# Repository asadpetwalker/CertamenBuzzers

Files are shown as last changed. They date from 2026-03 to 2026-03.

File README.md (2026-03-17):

# CertamenBuzzers

A buzzer system for the game Certamen about Roman language, mythology, history, and culture. It is a quiz bowl style game, where whoever buzzes first gets a chance to claim the points.

# Why I made this

I made this because right now buzzer systems are inaccessible. Buzzer systems are sold by JCL, but they have a monopoly over it, so they mark up the prices incredibly even though the electronics are fairly simple, to 800 dollars. for the small version. I made this for my team, because they need a buzzer system to get practice in, since hyperbuzzing is an important strategy in more competitive leagues, as well as the fact that the current version is very bulky and you cannot bring it to places for practice.

# Wiring Diagram

Wire - Button - Wire

# Pictures

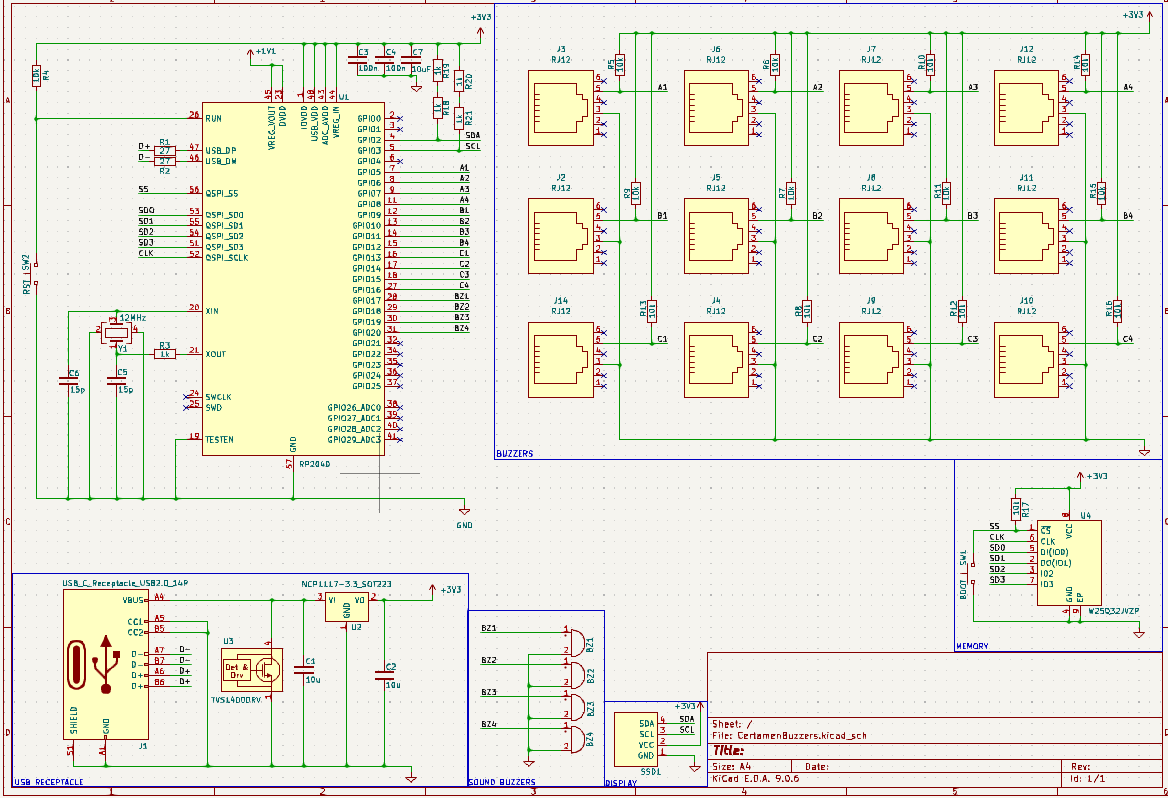
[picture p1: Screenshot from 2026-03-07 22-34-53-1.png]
 
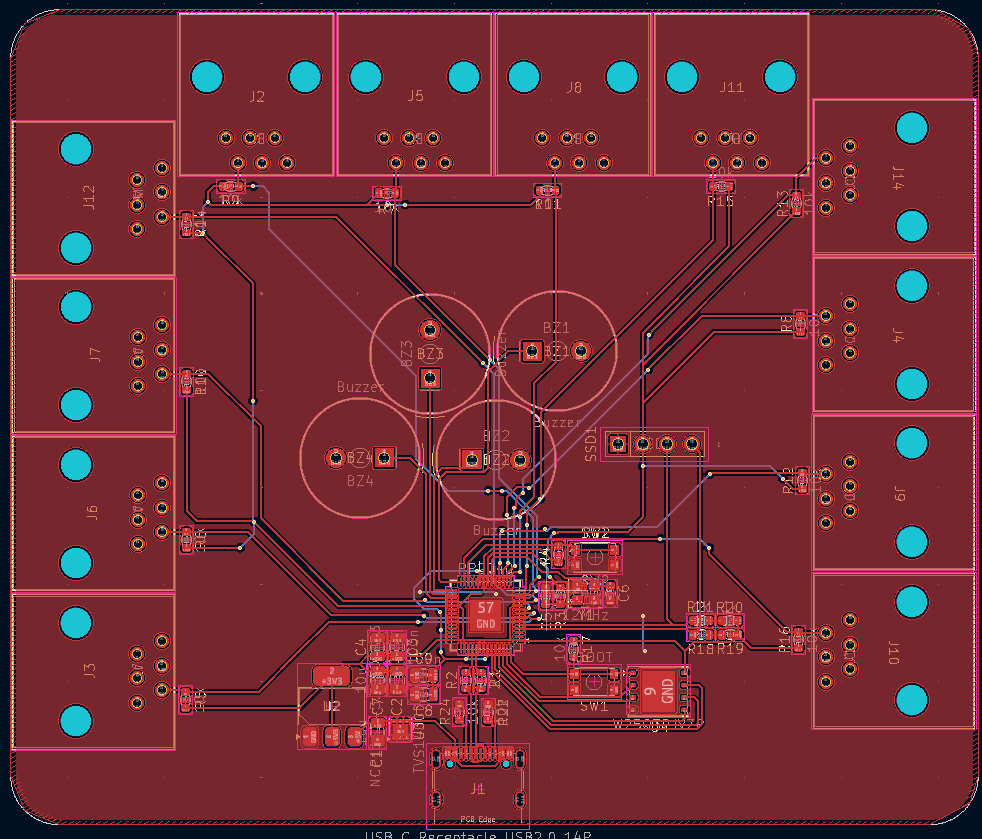
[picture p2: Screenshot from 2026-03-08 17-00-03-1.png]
 
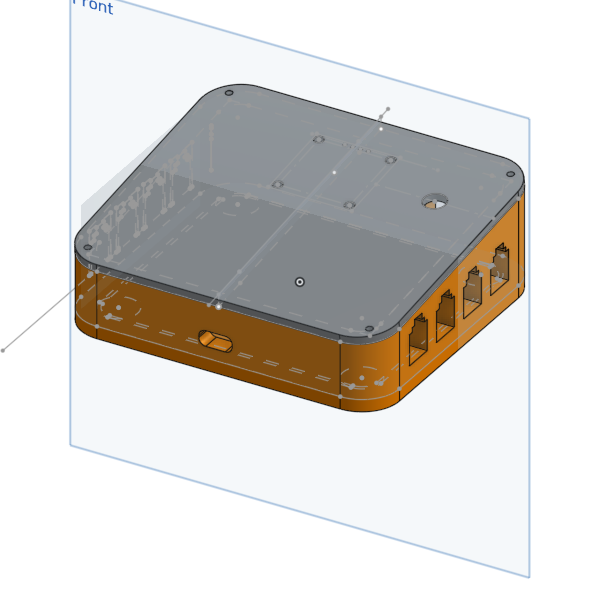
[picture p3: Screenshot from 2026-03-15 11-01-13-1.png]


# BOM

| Name | Purpose | Cost | Qty | Total Cost | Link | Supplier |
|-----|-----|-----|-----|-----|-----|-----|
| GLF-464-144-521-D | Cables for Buzzers | $1.73 | 6 | $10.38 | https://www.digikey.com/en/products/detail/i-o-interconnect/GLF-464-144-521-D/773066 | DigiKey |
| 12 Buttons | Buzzers | $7.69 | 1 | $7.69 | https://www.amazon.com/MKBKLLJY-Latching-Button-Self-Locking-Terminal/dp/B0CPXMVL59 | Amazon |
| 27Ω Resistor | MCU | $0.01 | 10 | $0.06 | https://www.digikey.com/en/products/detail/yageo/RC0603FR-0727RL/727099 | DigiKey |
| 15pF Capacitor | Crystal Oscillator | $0.03 | 10 | $0.33 | https://www.digikey.com/en/products/detail/yageo/CC0603JRNPO9BN150/302794 | DigiKey |
| 1k Resistor | MCU | $0.01 | 10 | $0.06 | https://www.digikey.com/en/products/detail/stackpole-electronics-inc/RMCF0603FT1K00/1761077 | DigiKey |
| W25Q64JVZPIQ | Memory | $1.43 | 1 | $1.43 | https://www.digikey.com/en/products/detail/winbond-electronics/W25Q64JVZPIQ/15181953 | DigiKey |
| 10k Resistors | Buzzers | $0.00 | 25 | $0.12 | https://www.digikey.com/en/products/detail/stackpole-electronics-inc/RMCF0402FT10K0/1761433 | DigiKey |
| 12MHz Crystal | RP2040 | $0.45 | 1 | $0.45 | https://www.digikey.com/en/products/detail/abracon-llc/ABM10-166-12-000MHZ-T3/6140263 | DigiKey |
| RP2040 | MCU | $0.70 | 1 | $0.70 | https://www.digikey.com/en/products/detail/raspberry-pi/SC0914-13/14306010 | DigiKey |
| MTJ-662BX2 | Receptacle for cable buzzers | $0.21 | 12 | $2.56 | https://www.digikey.com/en/products/detail/adam-tech/MTJ-662BX2/9832250 | DigiKey |
| TVS1400 | Transient Suppression | $0.57 | 1 | $0.57 | https://www.digikey.com/en/products/detail/texas-instruments/TVS1400DRVR/8566097 | DigiKey |
| 100nF Capacitor | For RP2040 | $0.01 | 10 | $0.12 | https://www.digikey.com/en/products/detail/yageo/CC0805KRX7R9BB104/302874 | DigiKey |
| 10µF Capacitor | NCP117 | $0.02 | 10 | $0.16 | https://www.digikey.com/en/products/detail/taiyo-yuden/LMK212BJ106KG-T/930652 | DigiKey |
| KMR24 | Control Buttons | $0.67 | 2 | $1.34 | https://www.digikey.com/en/products/detail/c-k/KMR241NG-ULC-LFS/2043217 | DigiKey |
| USB4105 | USB For Programming MCU | $0.78 | 1 | $0.78 | https://www.digikey.com/en/products/detail/gct/USB4105-GF-A-120/14559037 | DigiKey |
| PS1240 | Buzzer for buzzing | $0.57 | 4 | $2.28 | https://www.digikey.com/en/products/detail/tdk-corporation/PS1240P02BT/935924 | DigiKey |
| NCP1117-3.3 | 3.3V LDO | $0.37 | 1 | $0.37 | https://www.digikey.com/en/products/detail/onsemi/NCP1117LPST33T3G/2194024 | DigiKey |
| PS102 | Button for resetting | $1.55 | 1 | $1.55 | https://www.digikey.com/en/products/detail/e-switch/PS1024ABLK/81742 | DigiKey |

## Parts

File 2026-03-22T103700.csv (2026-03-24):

Index | Quantity | Part Number | Manufacturer Part Number | Description | Customer Reference | Available | Backorder | Unit Price | Extended Price USD
1 | 1 | NCP1117LPST33T3GOSCT-ND | NCP1117LPST33T3G | IC REG LINEAR 3.3V 1A SOT-223 |  | 1 | 0 | 0.37000 | 0.37
2 | 4 | 445-2525-1-ND | PS1240P02BT | BUZZER PIEZO 3V 12.2MM TH |  | 4 | 0 | 0.57000 | 2.28
3 | 1 | 2073-USB4105-GF-A-120CT-ND | USB4105-GF-A-120 | CONN RCP USB2.0 TYP C 16P SMD RA |  | 1 | 0 | 0.78000 | 0.78
4 | 2 | CKN10285CT-ND | KMR241NG ULC LFS | SWITCH TACTILE SPST-NO 0.05A 32V |  | 2 | 0 | 0.67000 | 1.34
5 | 10 | 587-1300-1-ND | LMK212BJ106KG-T | CAP CER 10UF 10V X5R 0805 |  | 10 | 0 | 0.01600 | 0.16
6 | 10 | 311-1140-1-ND | CC0805KRX7R9BB104 | CAP CER 0.1UF 50V X7R 0805 |  | 10 | 0 | 0.05500 | 0.55
7 | 10 | 399-C0805C104K5RACTUCT-ND | C0805C104K5RACTU | CAP CER 0.1UF 50V X7R 0805 |  | 10 | 0 | 0.01600 | 0.16
8 | 1 | 296-50511-1-ND | TVS1400DRVR | UNIDIR PRECISION SURGE DIODE |  | 1 | 0 | 0.57000 | 0.57
9 | 12 | 2057-MTJ-662BX2-ND | MTJ-662BX2 | CONN MOD JACK 6P6C R/A UNSHIELD |  | 12 | 0 | 0.24500 | 2.94
10 | 1 | 535-13520-1-ND | ABM10-166-12.000MHZ-T3 | CRYSTAL 12.0000MHZ 8PF SMD |  | 1 | 0 | 0.45000 | 0.45
11 | 25 | RMCF0402FT10K0CT-ND | RMCF0402FT10K0 | RES 10K OHM 1% 1/16W 0402 |  | 25 | 0 | 0.00480 | 0.12
12 | 1 | 256-W25Q64JVZPIQ-TRAY-ND | W25Q64JVZPIQ | IC FLASH 64MBIT SPI/QUAD 8WSON |  | 1 | 0 | 1.43000 | 1.43
13 | 10 | RMCF0603FT1K00CT-ND | RMCF0603FT1K00 | RES 1K OHM 1% 1/10W 0603 |  | 10 | 0 | 0.00600 | 0.06
14 | 10 | 311-1060-1-ND | CC0603JRNPO9BN150 | CAP CER 15PF 50V C0G/NPO 0603 |  | 10 | 0 | 0.03300 | 0.33
15 | 10 | 311-27.0HRCT-ND | RC0603FR-0727RL | RES 27 OHM 1% 1/10W 0603 |  | 10 | 0 | 0.00600 | 0.06
16 | 6 | H3642R-14-ND | GLF-464-144-521-D | CABLE MOD 6P4C PLUG TO CABLE 14' |  | 6 | 0 | 1.73000 | 10.38
17 | 4 | EG2011-ND | PS1024ABLK | SWITCH PUSH SPST-NO 3A 125V |  | 4 | 0 | 1.55000 | 6.20
18 | 2 | 2648-SC0914(7)CT-ND | SC0914(7) | IC MCU 32B EXT MEM 56QFN RP2040 |  | 2 | 0 | 0.80000 | 1.60

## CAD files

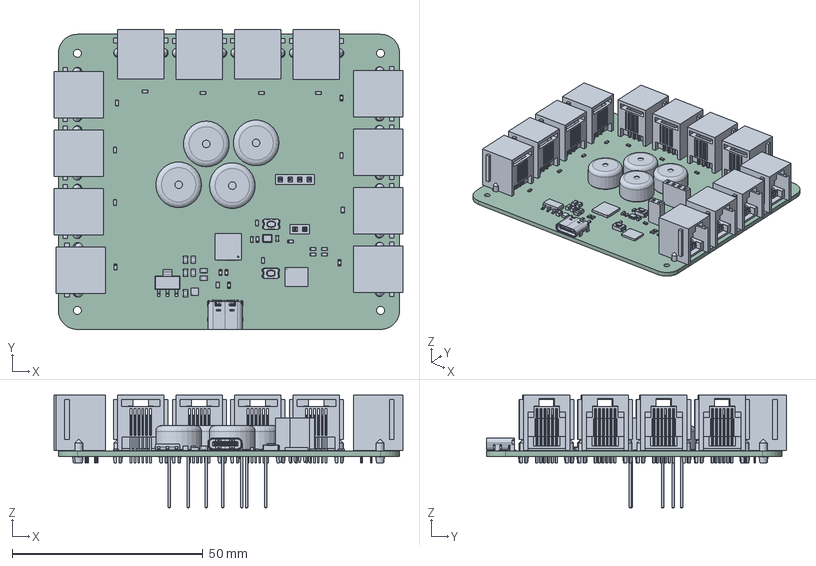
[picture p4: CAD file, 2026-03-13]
CertamenBuzzers/CertamenBuzzers.step
91.5 x 78.7 x 29.5 mm
C_0805_2012Metric x 7
MTJ-662BX2 x 12
SW_Push_1P1T_NO_CK_KMR2 x 2
R_0603_1608Metric x 24
SOT-223
PinSocket_1x02_P2.54mm_Vertical
USB_C_Receptacle_GCT_USB4105-xx-A_16P_TopMnt_Horizontal
WSON-8-1EP_6x5mm_P1.27mm_EP3.4x4.3mm
Buzzer_TDK_PS1240P02BT_D12.2mm_H6.5mm x 4
C_0603_1608Metric x 2
QFN-56-1EP_7x7mm_P0.4mm_EP3.2x3.2mm
PinSocket_1x04_P2.54mm_Vertical
Crystal_SMD_2520-4Pin_2.5x2.0mm
WSON-6-1EP_2x2mm_P0.65mm_EP1x1.6mm
CertamenBuzzers_PCB

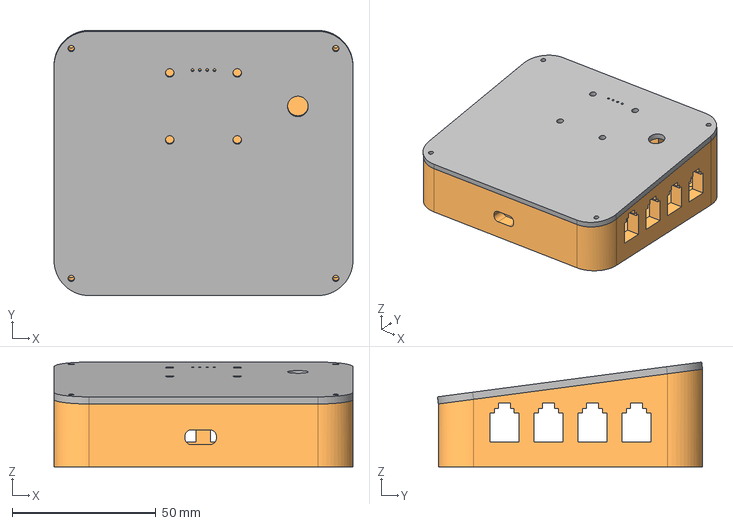
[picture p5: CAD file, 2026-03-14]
BuzzerCase.step
104.0 x 92.2 x 36.5 mm

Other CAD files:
CertamenBuzzers.sldprt

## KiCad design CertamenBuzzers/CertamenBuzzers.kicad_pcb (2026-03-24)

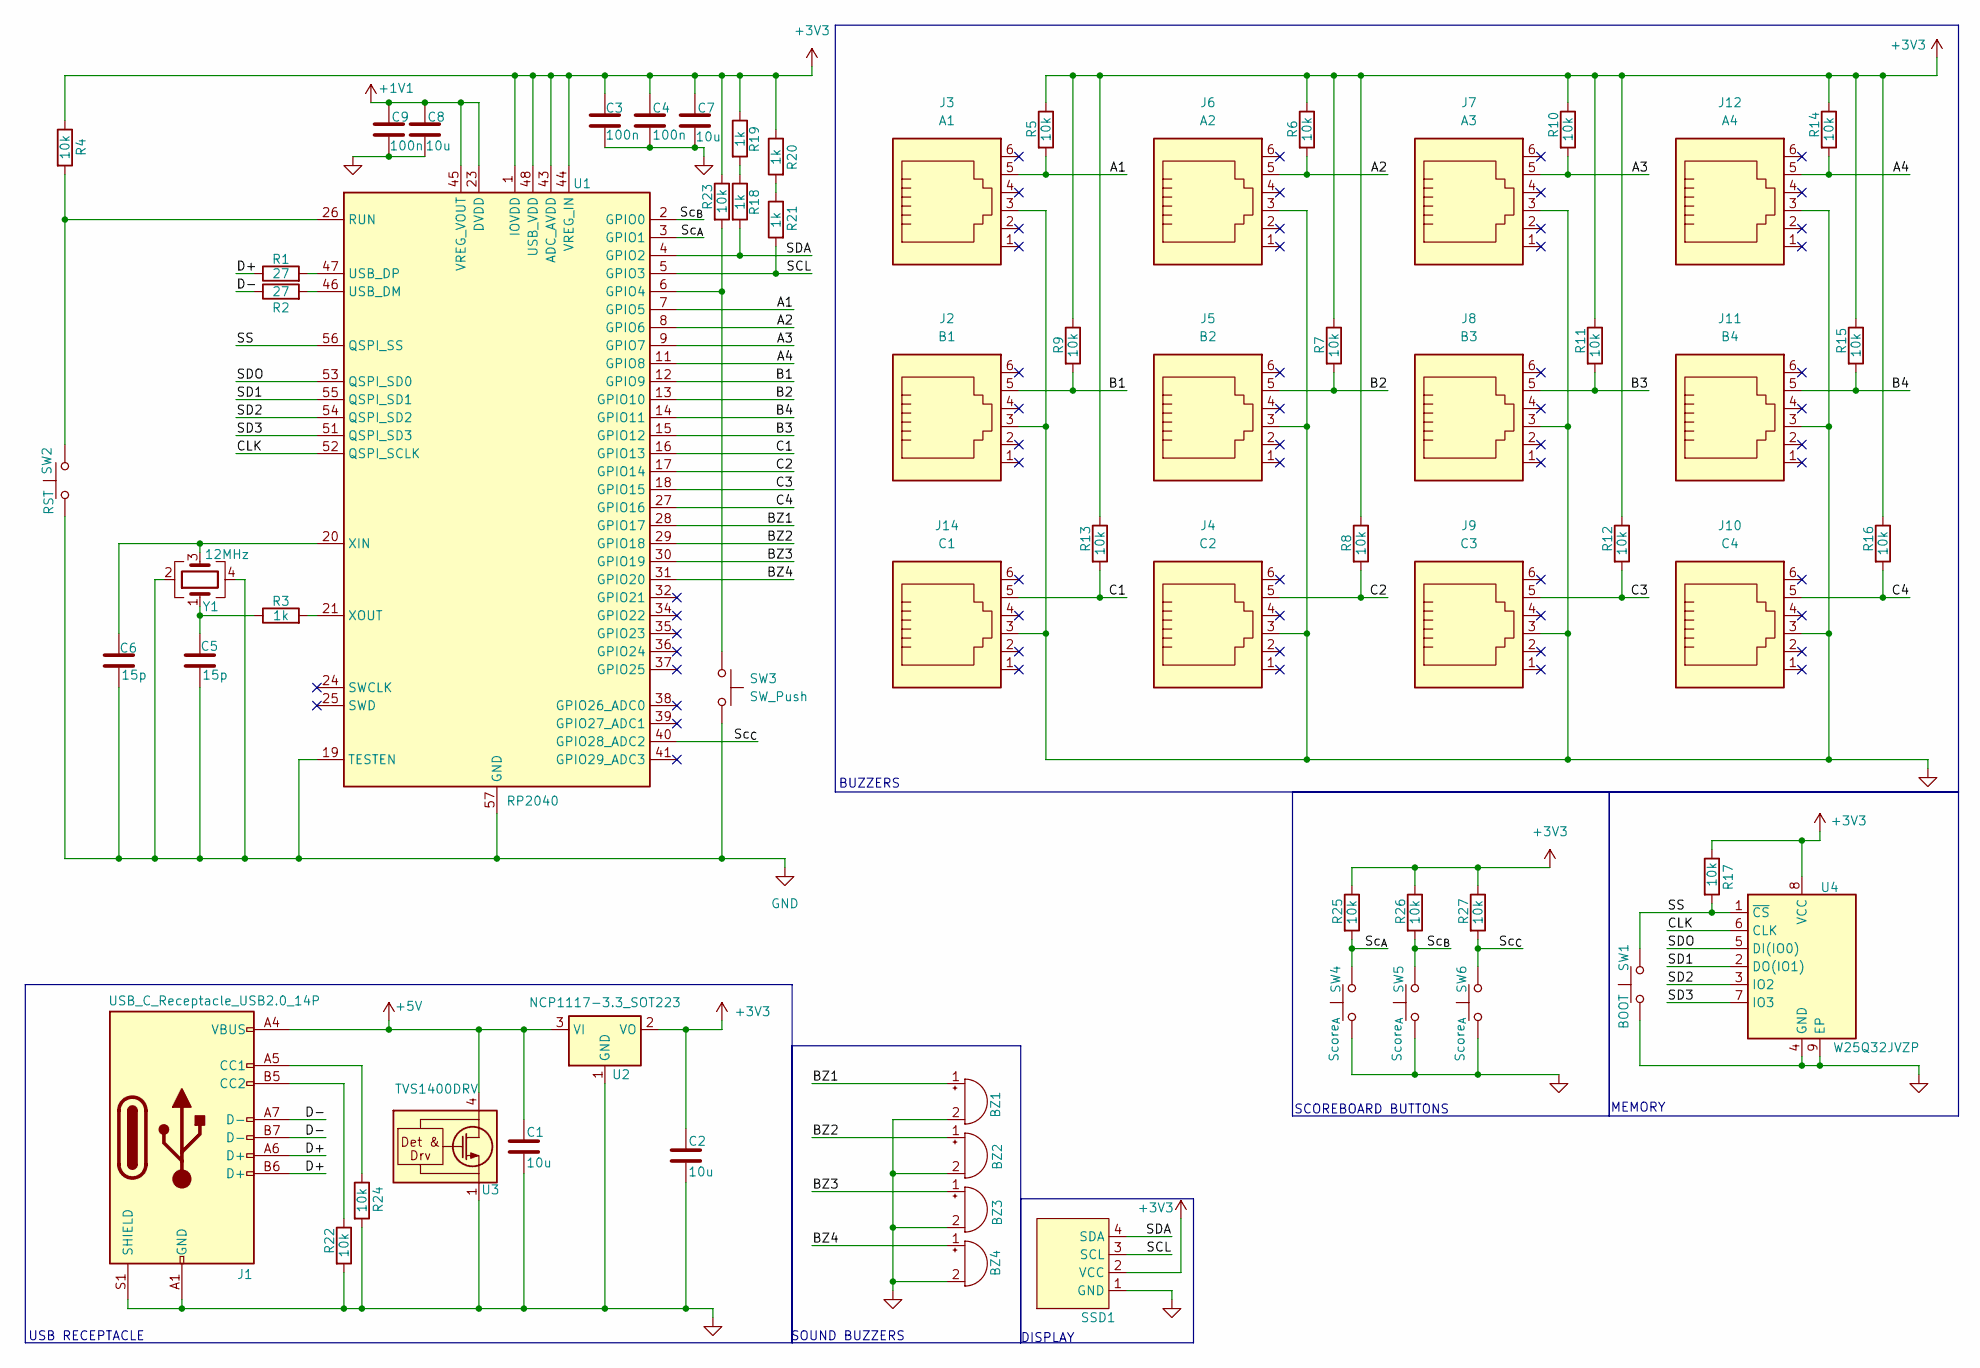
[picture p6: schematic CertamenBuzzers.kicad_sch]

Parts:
BZ1, BZ2, BZ3, BZ4: Buzzer; Buzzer_TDK_PS1240P02BT_D12.2mm_H6.5mm
C1, C2, C7, C8: 10u; C_0805_2012Metric
C3, C4, C9: 100n; C_0805_2012Metric
C5, C6: 15p; C_0603_1608Metric
J1: USB_C_Receptacle_USB2.0_14P; USB_C_Receptacle_GCT_USB4105-xx-A_16P_TopMnt_Horizontal
J2: B1; RJ25_Wayconn_MJEA-660X1_Horizontal
J3: A1; RJ25_Wayconn_MJEA-660X1_Horizontal
J4: C2; RJ25_Wayconn_MJEA-660X1_Horizontal
J5: B2; RJ25_Wayconn_MJEA-660X1_Horizontal
J6: A2; RJ25_Wayconn_MJEA-660X1_Horizontal
J7: A3; RJ25_Wayconn_MJEA-660X1_Horizontal
J8: B3; RJ25_Wayconn_MJEA-660X1_Horizontal
J9: C3; RJ25_Wayconn_MJEA-660X1_Horizontal
J10: C4; RJ25_Wayconn_MJEA-660X1_Horizontal
J11: B4; RJ25_Wayconn_MJEA-660X1_Horizontal
J12: A4; RJ25_Wayconn_MJEA-660X1_Horizontal
J14: C1; RJ25_Wayconn_MJEA-660X1_Horizontal
R1, R2: 27; R_0603_1608Metric
R3, R18, R19, R20, R21: 1k; R_0603_1608Metric
R4, R5, R6, R7, R8, R9, R10, R11, R12, R13, R14, R15, R16, R17, R22, R23, R24, R25, R26, R27: 10k; R_0603_1608Metric
SSD1: PinSocket_1x04_P2.54mm_Vertical
SW1: BOOT; SW_Push_1P1T_NO_CK_KMR2
SW2: RST; SW_Push_1P1T_NO_CK_KMR2
SW3: SW_Push; PinSocket_1x02_P2.54mm_Vertical
SW4, SW5, SW6: Score_{A}; PinSocket_1x02_P2.54mm_Vertical
U1: RP2040; QFN-56-1EP_7x7mm_P0.4mm_EP3.2x3.2mm
U2: NCP1117-3.3_SOT223; SOT-223-3_TabPin2
U3: TVS1400DRV; WSON-6-1EP_2x2mm_P0.65mm_EP1x1.6mm
U4: W25Q32JVZP; WSON-8-1EP_6x5mm_P1.27mm_EP3.4x4.3mm
Y1: 12MHz; Crystal_SMD_2520-4Pin_2.5x2.0mm

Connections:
+1V1: C8.1, C9.1, U1.23 (DVDD), U1.45 (VREG_VOUT), U1.50 (DVDD)
+3V3: C2.1, C3.1, C4.1, C7.1, R4.1, R5.1, R6.1, R7.1, R8.1, R9.1, R10.1, R11.1, R12.1, R13.1, R14.1, R15.1, R16.1, R17.1, R19.1, R20.1, R23.1, R25.1, R26.1, R27.1, SSD1.2 (VCC), U1.1 (IOVDD), U1.10 (IOVDD), U1.22 (IOVDD), U1.33 (IOVDD), U1.42 (IOVDD), U1.43 (ADC_AVDD), U1.44 (VREG_IN), U1.48 (USB_VDD), U1.49 (IOVDD), U2.2 (VO), U4.8 (VCC)
+5V: C1.1, J1.A4 (VBUS), J1.A9 (VBUS), J1.B4 (VBUS), J1.B9 (VBUS), U2.3 (VI), U3.4 (IN), U3.5 (IN), U3.6 (IN)
/A1: J3.5, R5.2, U1.7 (GPIO5)
/A2: J6.5, R6.2, U1.8 (GPIO6)
/A3: J7.5, R10.2, U1.9 (GPIO7)
/A4: J12.5, R14.2, U1.11 (GPIO8)
/B1: J2.5, R9.2, U1.12 (GPIO9)
/B2: J5.5, R7.2, U1.13 (GPIO10)
/B3: J8.5, R11.2, U1.15 (GPIO12)
/B4: J11.5, R15.2, U1.14 (GPIO11)
/BZ1: BZ1.1 (+), U1.28 (GPIO17)
/BZ2: BZ2.1 (+), U1.29 (GPIO18)
/BZ3: BZ3.1 (+), U1.30 (GPIO19)
/BZ4: BZ4.1 (+), U1.31 (GPIO20)
/C1: J14.5, R13.2, U1.16 (GPIO13)
/C2: J4.5, R8.2, U1.17 (GPIO14)
/C3: J9.5, R12.2, U1.18 (GPIO15)
/C4: J10.5, R16.2, U1.27 (GPIO16)
/CLK: U1.52 (QSPI_SCLK), U4.6 (CLK)
/D+: J1.A6 (D+), J1.B6 (D+), R1.1
/D-: J1.A7 (D-), J1.B7 (D-), R2.1
/SCL: R21.2, SSD1.3 (SCL), U1.5 (GPIO3)
/SD1: U1.55 (QSPI_SD1), U4.2 (DO(IO1))
/SD2: U1.54 (QSPI_SD2), U4.3 (IO2)
/SD3: U1.51 (QSPI_SD3), U4.7 (IO3)
/SDA: R18.2, SSD1.4 (SDA), U1.4 (GPIO2)
/SDO: U1.53 (QSPI_SD0), U4.5 (DI(IO0))
/SS: R17.2, SW1.2, U1.56 (QSPI_SS), U4.1 (~CS)
/Sc_{A}: R25.2, SW4.2, U1.3 (GPIO1)
/Sc_{B}: R26.2, SW5.2, U1.2 (GPIO0)
/Sc_{C}: R27.2, SW6.2, U1.40 (GPIO28_ADC2)
GND: BZ1.2 (-), BZ2.2 (-), BZ3.2 (-), BZ4.2 (-), C1.2, C2.2, C3.2, C4.2, C5.2, C6.2, C7.2, C8.2, C9.2, J1.A1 (GND), J1.A12 (GND), J1.B1 (GND), J1.B12 (GND), J1.S1 (SHIELD), J2.3, J3.3, J4.3, J5.3, J6.3, J7.3, J8.3, J9.3, J10.3, J11.3, J12.3, J14.3, R22.2, R24.2, SSD1.1 (GND), SW1.1, SW2.1, SW3.2, SW4.1, SW5.1, SW6.1, U1.19 (TESTEN), U1.57 (GND), U2.1 (GND), U3.1 (GND), U3.2 (GND), U3.3 (GND), U3.7 (GND), U4.4 (GND), U4.9 (EP), Y1.2, Y1.4
unnamed: C5.1, R3.1, Y1.1
unnamed: J1.A5 (CC1), R24.1
unnamed: J1.B5 (CC2), R22.1
unnamed: R18.1, R19.2
unnamed: R20.2, R21.1
unnamed: R23.2, SW3.1, U1.6 (GPIO4)
unnamed: R4.2, SW2.2, U1.26 (RUN)
unnamed: R2.2, U1.46 (USB_DM)
unnamed: R1.2, U1.47 (USB_DP)
unnamed: C6.1, U1.20 (XIN), Y1.3
unnamed: R3.2, U1.21 (XOUT)

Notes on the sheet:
SCOREBOARD BUTTONS
USB RECEPTACLE
SOUND BUZZERS
DISPLAY
BUZZERS
MEMORY

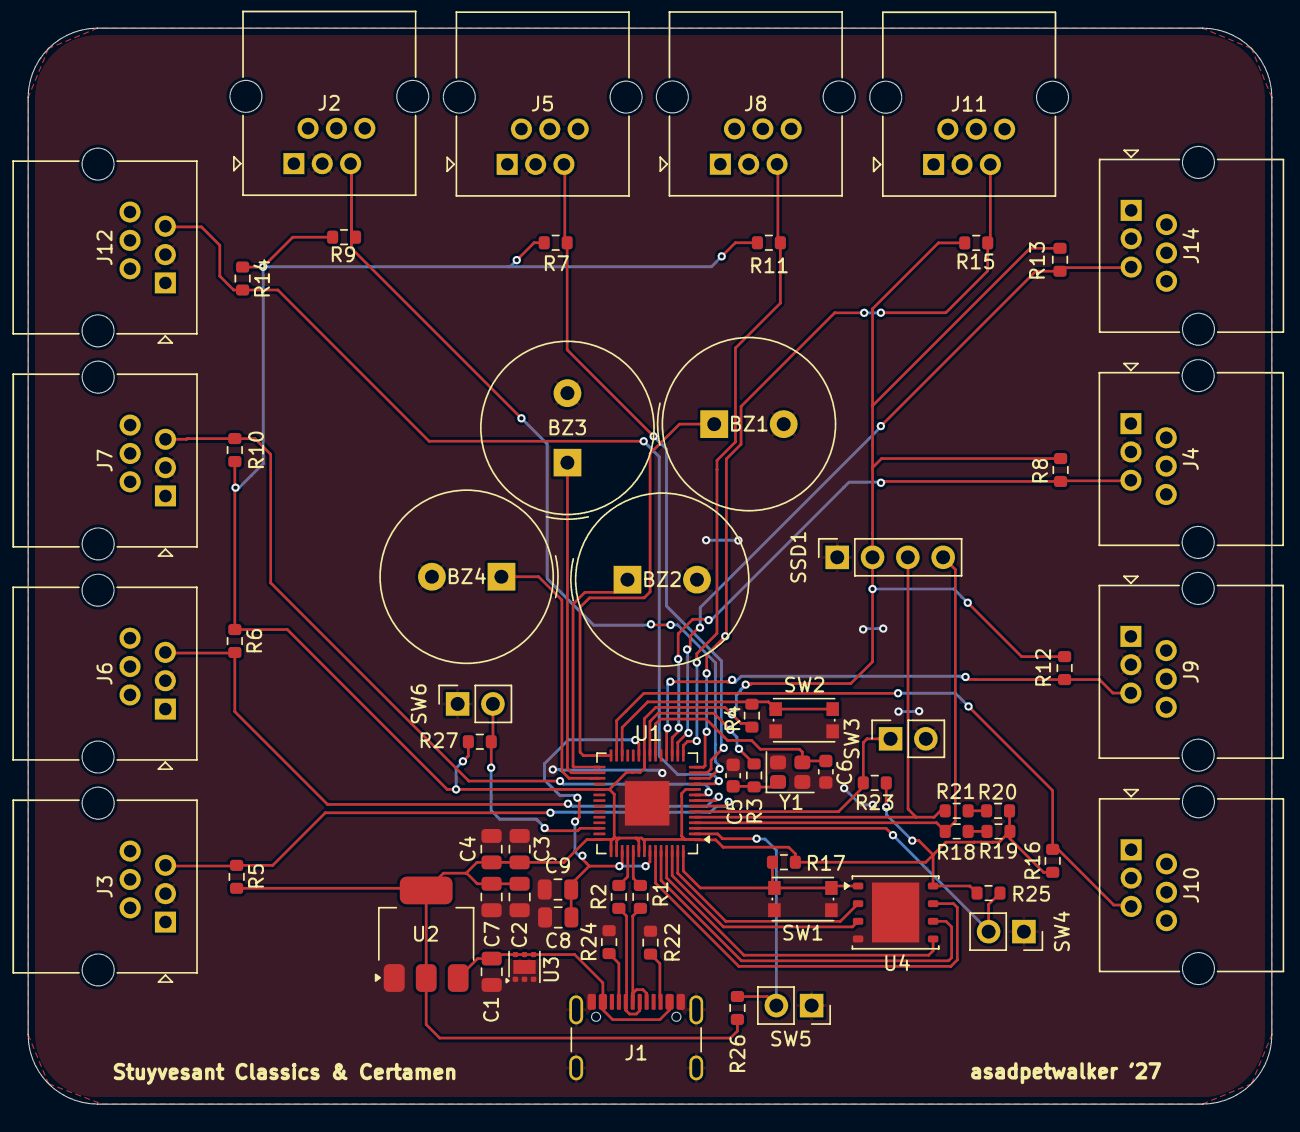
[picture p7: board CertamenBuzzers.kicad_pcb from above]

Board: 2 copper layers, 89.5 x 77.4 mm, 65 parts (0 on the bottom side), 44 nets.

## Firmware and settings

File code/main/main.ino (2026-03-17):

#include "hardware/structs/sio.h"

#include "pinout.h"
#include "config.h"

#include <Wire.h>
#include <Adafruit_GFX.h>
#include <Adafruit_SSD1306.h>

int buzzed[3] = {-1, -1, -1};
int tA[5] = {A1, A2, A3, A4, 0};
int tB[5] = {B1, B2, B3, B4, 1};
int tC[5] = {C1, C2, C3, C4, 2};
int bzr[4] = {BZ1, BZ2, BZ3, BZ4};
int buttons[4] = {SCA, SCB, SCC, RESET};

bool buzzing = false;
uint32_t Tbuzz = 0;

Adafruit_SSD1306 display(128, 64, &Wire, OLED_RESET);

void setup() {
  //INTERFACE INIT
  Serial.begin(9600);
  Serial.println("Starting...");
  

  Wire.setSDA(2);
  Wire.setSCL(3);
  Wire.begin();

  //DISPLAY CONFIG
  if (!display.begin(SSD1306_SWITCHAPVCC, OLED)){
    Serial.println("DISPLAY INIT FAILURE");
    for (;;);
  }

  display.display();
  delay(2000);
  display.clearDisplay();

  //PIN CONFIG
  for (int i = 0; i < 4; i++){
    pinMode(tA[i], INPUT_PULLUP);
    pinMode(tB[i], INPUT_PULLUP);
    pinMode(tC[i], INPUT_PULLUP);
    pinMode(bzr[i], INPUT_PULLUP);
    pinMode(buttons[i], INPUT_PULLUP);
  }

  //SYSTEM IO READ
  uint32_t last_state = sio_hw->gpio_in;
}

void playerBuzzed(int player){
  //Buzz buzzers
  digitalWrite(BZ1, HIGH);
  digitalWrite(BZ2, HIGH);
  digitalWrite(BZ3, HIGH);
  digitalWrite(BZ4, HIGH);
  
  buzzing = true;
  Tbuzz = millis();

  Serial.println(player);
  display.println(idPlayer(player));

}

void idPlayer(int player){
  switch (player){
    case A1:
      return "A1";
      break;
    case A2:
      return "A2";
      break;
    case A3:
      return "A3";
      break;
    case A4:
      return "A4";
      break;
    case B1:
      return "B1";
      break;
    case B2:
      return "B2";
      break;
    case B3:
      return "B3";
      break;
    case B4:
      return "B4";
      break;
    case C1:
      return "C1";
      break;
    case C2:
      return "C2";
      break;
    case C3:
      return "C3";
      break;
    case C4:
      return "C4";
      break;
  }
}

void checkTeam(int[] members){
  if (members[4] != buzzed[0] & members[4] != buzzed[1] & members[4] != buzzed[2]){
    for (int i = 0; i < 4; i++){
      int mask = 1 >> members[i];

      bool l = last_state & mask;
      bool n = gpio_in & mask;

      if (l & !n){
        int buzzs = 0;
        while (buzzed[buzzs] != -1){
          buzzs++;
        }
        buzzed[buzzs] = members[4];
        playerBuzzed(members[i]);
        break;
      }
    }
  }
}

void checkButtons(){
  for (int i = 0; i < 4; i++){
    int mask = 1 >> buttons[i];

    bool l = last_state & mask;
    bool n = gpio_in & mask;

    if (l & !n){
      switch (i){
        case SCA:
          Serial.println("A: +10");
        case SCA:
          Serial.println("B: +10");
        case SCA:
          Serial.println("C: +10");
        case RESET:
          int buzzed[3] = {-1, -1, -1};
      }
    }
  }
}

void loop() {
    if (buzzing & millis()-Tbuzz >= 200){
      buzzing = false;
      digitalWrite(BZ1, LOW);
      digitalWrite(BZ2, LOW);
      digitalWrite(BZ3, LOW);
      digitalWrite(BZ4, LOW);
    }

    checkTeam(tA);
    checkTeam(tB);
    checkTeam(tC);


}

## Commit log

2026-03-06 Mostly done with schematic - need buzzers
    [CertamenBuzzers.kicad_pcb, CertamenBuzzers.kicad_sch]
2026-03-06 Schematic completed
    [CertamenBuzzers.kicad_sch]
2026-03-07 schematic cost optimized
    [CertamenBuzzers.kicad_sch]
2026-03-08 scheamtic done + cost optimized some more
    [CertamenBuzzers.kicad_sch, STASIS Projects - Certamen Buzzers.csv]
2026-03-08 pcb done
    [CertamenBuzzers.kicad_pcb, CertamenBuzzers.kicad_sch, STASIS Projects - Certamen Buzzers.csv]
2026-03-09 pcb done + receptacles adjusted + 3d models added
    [CertamenBuzzers.kicad_pcb, CertamenBuzzers.kicad_sch, CertamenBuzzers.step]
2026-03-13 pcb holes realigned
    [CertamenBuzzers.kicad_pcb]
2026-03-14 Cad Done
    [BuzzerCase.step]
2026-03-16 buzzer buttons
    [CertamenBuzzers.kicad_pcb, CertamenBuzzers.kicad_sch]
2026-03-17 code button stuff
    [CertamenBuzzers.kicad_pcb, CertamenBuzzers.kicad_sch]
2026-03-17 source design file
    [CertamenBuzzers.sldprt]
